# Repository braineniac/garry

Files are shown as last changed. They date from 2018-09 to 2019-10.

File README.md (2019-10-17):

# Project Garry

My bachelor's project at TU Vienna. A small snail-like robot with localization capabilities.  

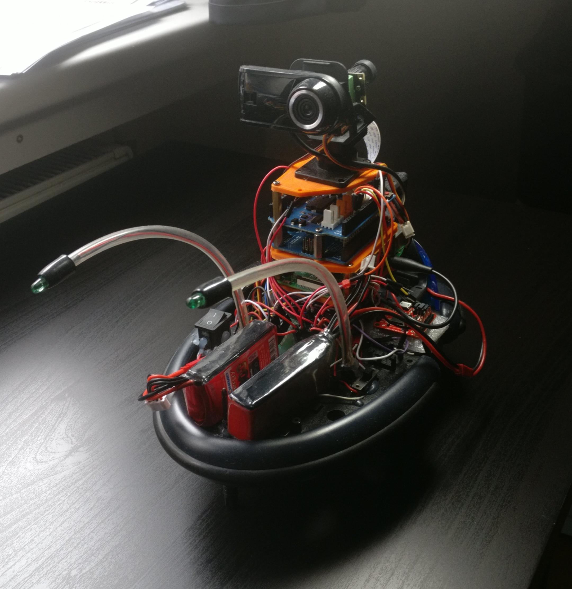
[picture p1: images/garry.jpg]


The repos used in this project are:  
- Kalman filters: https://github.com/braineniac/kalman_estimator.git  
- Low level nodes: https://github.com/braineniac/garry-robot.git  
- Arduino firmware: https://github.com/braineniac/garry-firmware.git  
- URDF: https://github.com/braineniac/garry-description.git  
- MPU6050 driver node: https://github.com/braineniac/rpi_mpu6050.git  

## Hardware  

- Raspberry Pi 3 Model B  Rev 1.2  
- Arduino Uno Rev3  
- Arduino Motor Shield Rev3    
- Raspberry Pi Night Vision Camera Module(OV5647 5MP Webcam Sensor)  
- Logitech C905 Webcam  
- MPU-6050(later replaced with Razor 9dof IMU)
- Logitech Dual Action Gamepad  
- 2 green LEDs  
- 2x generic 5V DC motors  
- 2x EMAX ES08MA II 12g Mini Metal Gear Analog Servo

# Useful tutorials  

## Swap setup for compiling on the Raspberry Pi  

Get an empty USB drive, in this case it shows up as /dev/sda. Create a partition on it and format it as ext4.  

Add an entry to /etc/fstab with the PARTUUID of the USB and automount to /swap.

Edit /etc/dphys-swapfile and uncomment all options and leave them empty(this will override all swap restrictions put in place), except the CONF_SWAPFILE=/swap/swapfile.  

Create swapfile in /swap:  
`$ sudo dd if=/dev/zero of=/swap/swapfile bs=1G count=7 status=progress`  
`$ sudo mkswap /swap/swapfile`  

Disable dphys-service:  
`$ sudo systemctl disable dphys-swapfile`  
`$ sudo systemctl stop dphys-swapfile`  

Now you can mount the swapfile:  
`$ sudo swapon /swap/swapfile`  

Check if it worked with:  
`$ free -m`  

## WIFI access point setup  

Replace the firmware with the [new][7] one.  

Install hostapd and dnsmasq  
`$ sudo apt install hostapd dnsmasq dhcpcd5 -y`  

Stop the services for now:  
`$ sudo systemctl stop dnsmasq hostapd`  

Run:  
`$ ./scripts/wifi.sh`  
`$ ./scripts/services.sh`  

Then reboot and it should work. The default password is g4rryn3t and can be changed in the dnsmasq.conf file.  

## Workspace setup  

Create new folder:  
`$ mkdir -p ros_ws/src && cd ros_ws`  

Setup workspace with wstool:  
`$ wstool init src GARRY_DIR/.rosinstall`  

Compile with:  
`$ catkin build `  

[1]: http://wiki.ros.org/melodic/Installation/Source
[2]: https://answers.ros.org/question/294780/ubuntu18-and-ros-melodic-catkin-error-importerror-no-module-named-terminal_color/
[3]: https://github.com/ros/catkin/pull/975
[4]: https://gitlab.kitware.com/cmake/cmake/merge_requests/2570/commits
[5]: https://gitlab.kitware.com/cmake/cmake/issues/18638
[6]: https://www.raspberrypi.org/documentation/configuration/wireless/access-point.md
[7]: https://github.com/RPi-Distro/firmware-nonfree

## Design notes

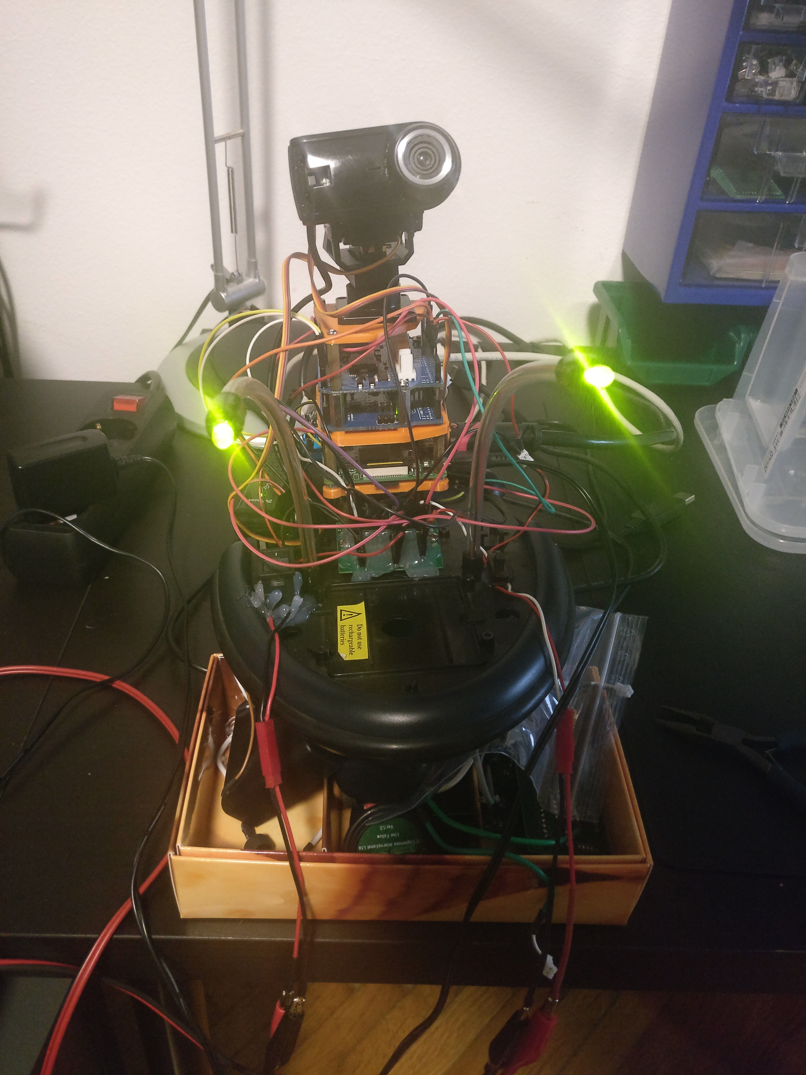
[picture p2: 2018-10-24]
images/arduino_done.jpg

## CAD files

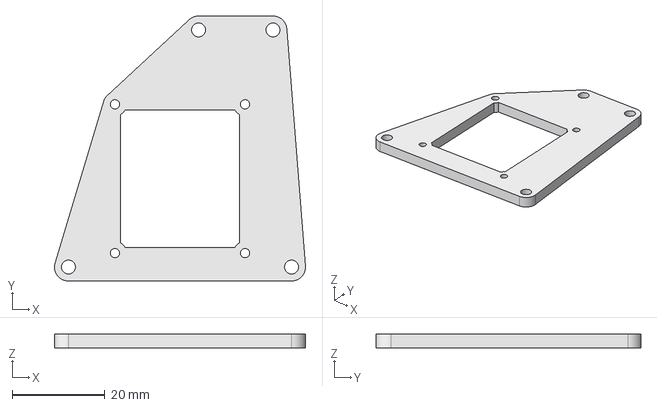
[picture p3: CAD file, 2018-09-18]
models/top.fcstd
54.0 x 57.0 x 3.00 mm

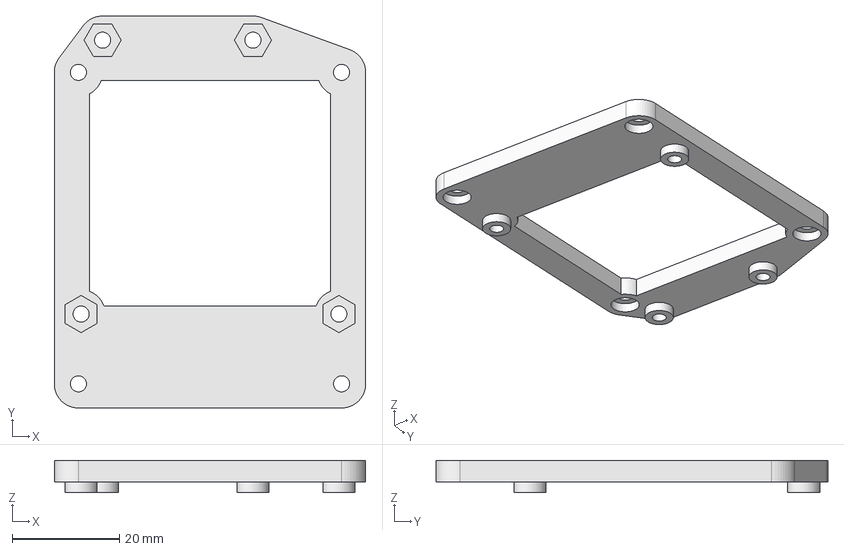
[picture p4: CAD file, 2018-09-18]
models/RaspiToUNO.fcstd
58.0 x 73.0 x 6.00 mm

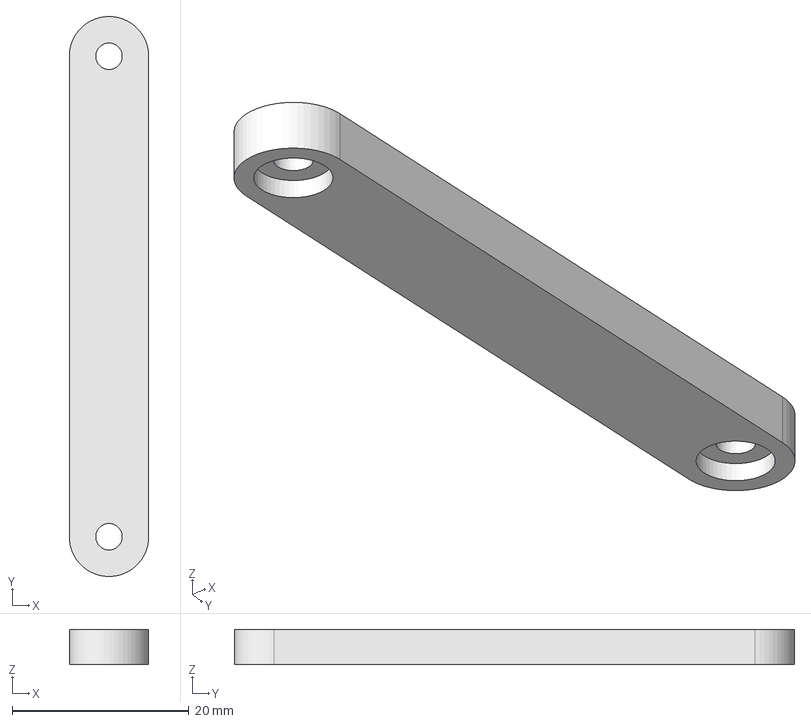
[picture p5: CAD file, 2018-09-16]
models/USB_plate.fcstd
9.00 x 63.4 x 4.00 mm

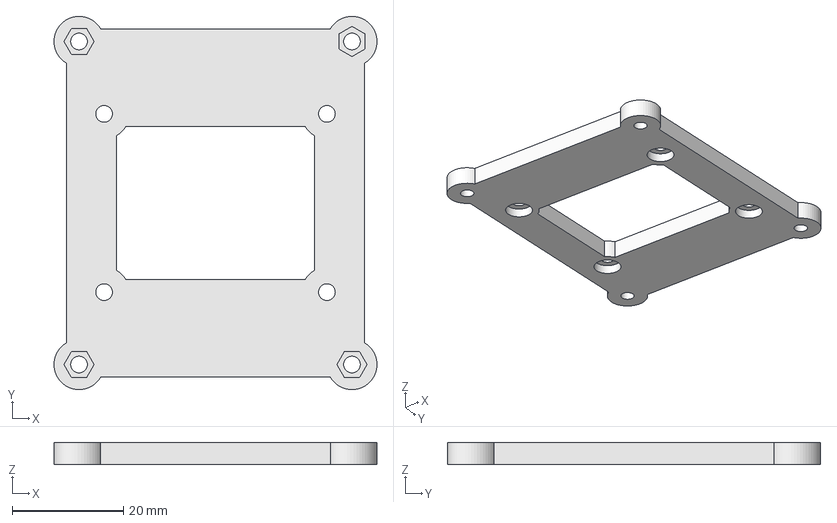
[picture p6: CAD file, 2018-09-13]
models/baseToRaspi.fcstd
58.0 x 67.0 x 4.00 mm

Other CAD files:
models/RaspiToUNO.obj
models/USB_plate.obj
models/baseToRaspi.obj
models/top.obj

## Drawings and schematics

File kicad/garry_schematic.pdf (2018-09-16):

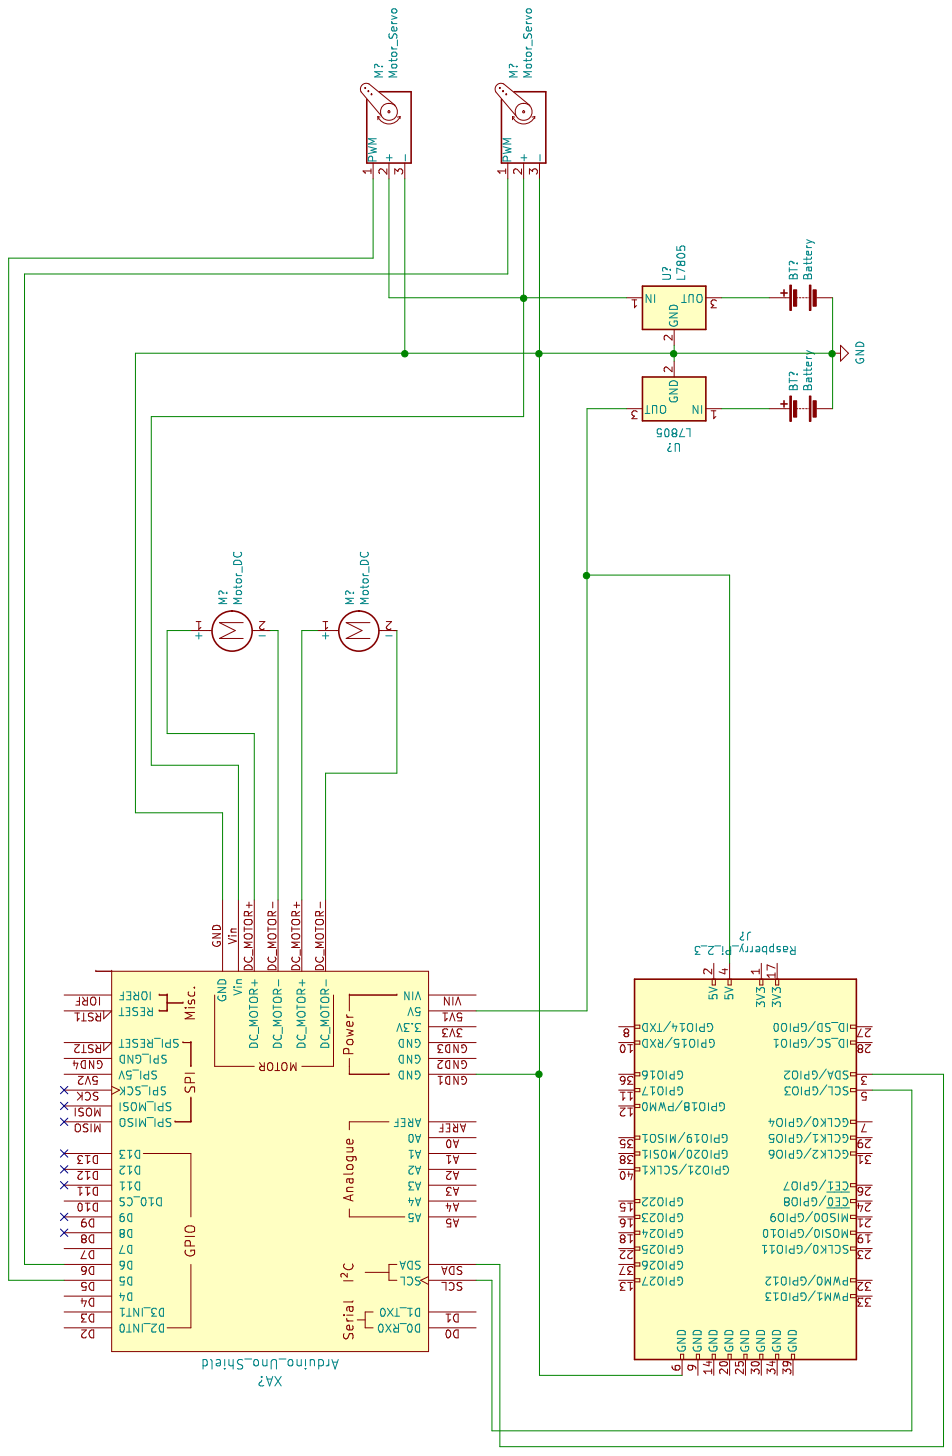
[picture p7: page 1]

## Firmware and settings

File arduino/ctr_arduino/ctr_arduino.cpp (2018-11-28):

#include <Arduino.h>
#include <SoftwareSerial.h>
#include <Wire.h>
#include <Servo.h>

#define SLAVE_ADDR 0x04

#define ENABLE_LOG //comment out to disable logging
#define VALID_DATA 42

/* macro functions */
#ifdef ENABLE_LOG
#define LOG(x)  {  Serial.println(x); }
#else
#define LOG(x) // do nothing
#endif

Servo servoA;
Servo servoB;

void call_function(int fnum, int param1, int param2, int param3,int param4);
void set_LEDs(int led1, int led2);
void motor_move(int A_dir, int B_dir, int A_speed, int B_speed);
void servo_move(int posA, int posB);
void receive_data_cb(int byteCount);
void send_data_cb();



 
void setup() {

    /* starting serial */
    Serial.begin(9600);
    LOG("[INIT] Serial begin");
    LOG("[INIT] Starting initialisation")
 
    /* initialize i2c as slave */
    Wire.begin(SLAVE_ADDR);
    LOG("[INIT] I2C slave initialised");

    /* initialise motor shield */
    //Setup Channel A
    pinMode(12, OUTPUT); //Initiates Motor Channel A pin
    pinMode(9, OUTPUT); //Initiates Brake Channel A pin

    //Setup Channel B
    pinMode(13, OUTPUT); //Initiates Motor Channel A pin
    pinMode(8, OUTPUT);  //Initiates Brake Channel A pin
    LOG("[INIT] Motor shield intialised")


    /* initialise servos */
    servoA.attach(5);
    servoB.attach(6);
    LOG("[INIT] Servos initialised");

    /* initialise LEDs */
    pinMode(4, OUTPUT);
    pinMode(7, OUTPUT);
    LOG("[INIT] LEDs initialised");
    
    /* define callbacks for i2c */
    Wire.onReceive(receive_data_cb);
    Wire.onRequest(send_data_cb);
    LOG("[INIT] I2C callbacks defined")

    LOG("[INIT] Initialisation completed")

}

/* main loop */
void loop() {
  
    //LOG("[LOOP] Starting loop")
    delay(100);
}

/* function selection */
void call_function(int fnum, int param1, int param2, int param3,int param4) {
    
    switch(fnum) {
          
          case 0:
              break;
          
          case 1:
              LOG("Calling function motor_move");
              motor_move(param1,param2,param3,param4);
              break;
          case 2:
              LOG("Calling servo_move");
              servo_move(param1,param2);
              break;
          case 3:
              LOG("Calling set_LEDs");
              set_LEDs(param1,param2);
              break;
          
          default:
              LOG("Invalid function call");
              break;
    }
    
}

void set_LEDs(int led1, int led2) {
  
        digitalWrite(4, led1);
        digitalWrite(7, led2);
}

void motor_move(int A_dir, int B_dir, int A_speed, int B_speed) {

        int n;
        LOG("[MOTOR_MOVE] Motor is moving");
        for(n=0;n<100;n++) {
        digitalWrite(12, !A_dir); // A motor forward(weird wiring)
        digitalWrite(9, LOW); // disable A motor brake 
        analogWrite(3, A_speed);

        digitalWrite(13, B_dir); // B motor forward
        digitalWrite(8, LOW); // disable B motor brake 
        analogWrite(11, B_speed);

        delay(1000); // run motor for 200 microseconds

        digitalWrite(9, HIGH); // enable A motor brake
        digitalWrite(8, HIGH); // enable B motor brake
        }
}

void servo_move(int posA, int posB) {
        if (posA >=10 && posA <=200 && posB <=90) {
            LOG("[SERVO_MOVE] Servo moving into position");
            LOG("[SERVO_MOVE] position of A");
            LOG(posA);
            LOG("[SERVO_MOVE] position of B");
            LOG(posB);
            servoA.write(posA); //60
            servoB.write(posB); //90
        }
        else {
            LOG("[SERVO_MOVE] Invalid parameters")
        }
        
        
}

/* callback for received data */
void receive_data_cb(int byteCount){

    int valid_data = 0;
    int function = 0;
    int param1 = 0;
    int param2 = 0;
    int param3 = 0;
    int param4 = 0;

    LOG("[RECEIVE_DATA_CB] Receiving data");
    int c;
    // reading from the I2C bus
    while(Wire.available()) {
        
        // data valiadation check
        valid_data = Wire.read();
        if(valid_data != VALID_DATA) {
            LOG("[RECEIVE_DATA_CB] Data validation check failed");
            break;
        }
        // validation check successful
        else {
            LOG("[RECEIVE_DATA_CB] Data validation check passed");
            
            function = Wire.read();
            LOG("[RECEIVE_DATA_CB] Reading function:");
            LOG(function);
            delay(50);
        
            param1 = Wire.read();
            LOG("[RECEIVE_DATA_CB] Reading param1:");
            LOG(param1);
            delay(50);
        
            param2 = Wire.read();
            LOG("[RECEIVE_DATA_CB] Reading param2:");
            LOG(param2);
            delay(50);

            param3 = Wire.read();
            LOG("[RECEIVE_DATA_CB] Reading param3:");
            LOG(param3);
            delay(50);

            param4 = Wire.read();
            LOG("[RECEIVE_DATA_CB] Reading param4:");
            LOG(param4);
            
            call_function(function,param1,param2,param3,param4);
            
        }
        
        //c = Wire.read();
        //LOG(c);
    }
}
 
/* callback for sending data */
void send_data_cb() {
    LOG("[SEND_DATA_CB] Sending data")
    Wire.write(99); // TODO
}

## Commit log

2018-08-01 Started working on the base model
    [garry_base.fcstd]
2018-08-01 Finished raspi plate scetch
    [raspi_plate.fcstd]
2018-08-26 Scetch almost done
    [raspi_plate.fcstd]
2018-09-11 Added baseToRaspi model
    [baseToRaspi.fcstd, baseToRaspi.obj, garry_base.fcstd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]
2018-09-13 Final baseToRaspi
    [baseToRaspi.fcstd, baseToRaspi.obj]
2018-09-16 Added kicad schematic, some arduino scetches, RaspiToUNO part
    [RaspiToUNO.fcstd, RaspiToUNO.obj, USB_plate.fcstd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]
2018-09-18 Fixed RaspiToUNO, added Top plate
    [RaspiToUNO.fcstd, RaspiToUNO.obj, top.fcstd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]
2018-10-07 Motor Quarter test+I2C
2018-10-12 Switching to ROS kinetic
2018-10-12 Restructured project, hopefully fixed snap
    [ctr_arduino.cpp]
2018-10-23 Finished motor control
2018-10-23 arduino motor control works
2018-10-23 arduino functions done
2018-10-23 arduino testfunctions added
2018-10-24 implemented motor timing
2018-11-28 Headless arduino setup done
2018-11-28 moved arduino files
2018-11-28 ROSified leds, removed wire
2018-12-07 Arduino rosserial finally working
2018-12-15 Arduino firmware complete
2018-12-15 Added 6050 imu ROS node
2018-12-17 inital urdf
    [garry.urdf]
2018-12-18 added orbslam2
    [garry.urdf]
2018-12-19 Added camera calibration file
2018-12-26 added xacro to urdf, created garry-description
    [CropDecimate.cfg, Debayer.cfg, Disparity.cfg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]
2019-01-09 replaced nodes with rosinstall, added wifi configs
    [ctr_arduino.cpp]
